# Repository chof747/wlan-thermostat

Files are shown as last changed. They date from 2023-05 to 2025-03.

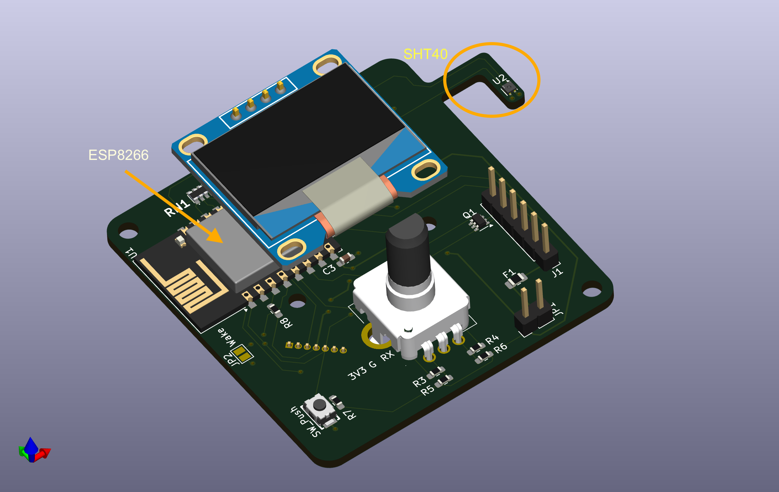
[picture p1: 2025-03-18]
temp_issue/wlan-thermo-front-panel-1.png

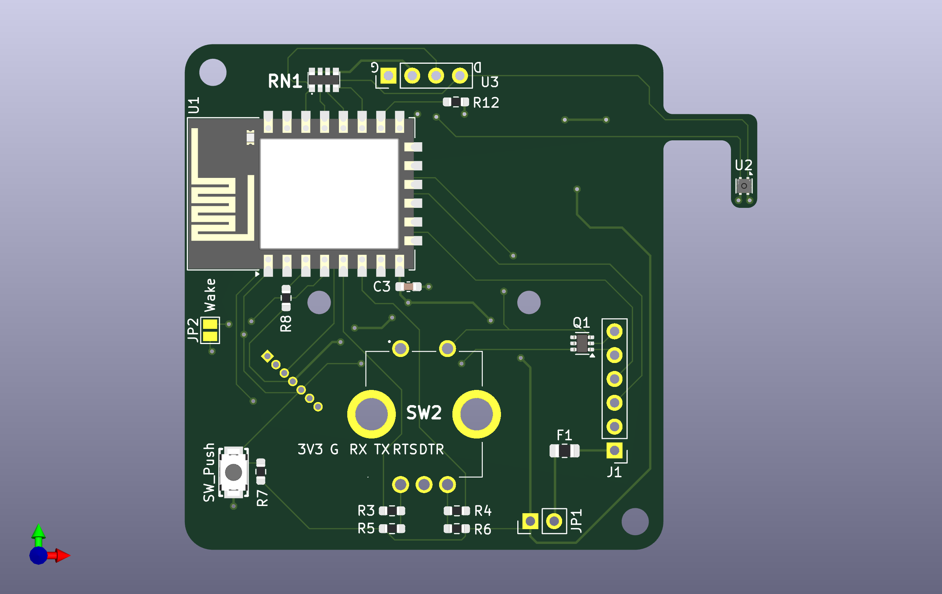
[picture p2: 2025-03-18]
temp_issue/wlan-thermo-front-panel-2.png

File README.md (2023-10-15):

## wlan-thermostat
Wireless Thermostats for elecrically triggerd heatings

This is the front panel of a wireless triggered heating which can be connected to a second board that contains the 
power supply and a relais capeable of switching the required electrical load. The front panel is designed to be
attached in a perpendicular way to the back part.

### Elements:

- An ESP8266-12F module containing the microcontroller, Flash
- A SHT40 temperature and humidity sensor
- A rotary encoder for input
- A SSD1306 OLED display for output
- Voltage regulator to regulate the 5V from the back board to 3v3 for the ESP8266 
- Programming logic and headers
- Headers to connect to the back board for power control and relay switching

## Used Parts:

## Revision History:

- **v1.0**: Initial version (Produced: 12.06.2023; First assembled: 29.06.2023)
- **v1.1**: Fixing after component testin (Produced: 15.07.2023; First assembled: 31.07.2023 / Frontend)
   1. Frontend:
     - Fixing of strapping pins of ESP-12F
     - Fixing of thermocoupling between ESP-12F and the temperature sensor
     - Introduction of UMH3N chip to replace two transistors + two resistors for the auto-reset circuit
     - Introduced resistor array to manage strapping pins
     - Switching of pins as follows:
         - Rotary Encoder Button now GPIO0 (doubling as a fallback mode for programming)
         - Relay pin: GPIO13

   2. Backend
     - Fixed orientation of Relay Footprint
     - Fixed size of footprint for optocoppler
     - Changed pinheaders for frontend connection from smd to throughole
     - Rearranged board placing to manage changed footprints
- **v1.2**: Alternate version without (exposed) ground panel at the back of the frontend thermo sensor
- **v1.3b**: Moved the temperature sensor to a sidearm sticking out of the board (produced 18.09.2023)
- **v1.2 (backend)**: Corrected pin order of transistor switching relay (Produced: 15.10.2023)

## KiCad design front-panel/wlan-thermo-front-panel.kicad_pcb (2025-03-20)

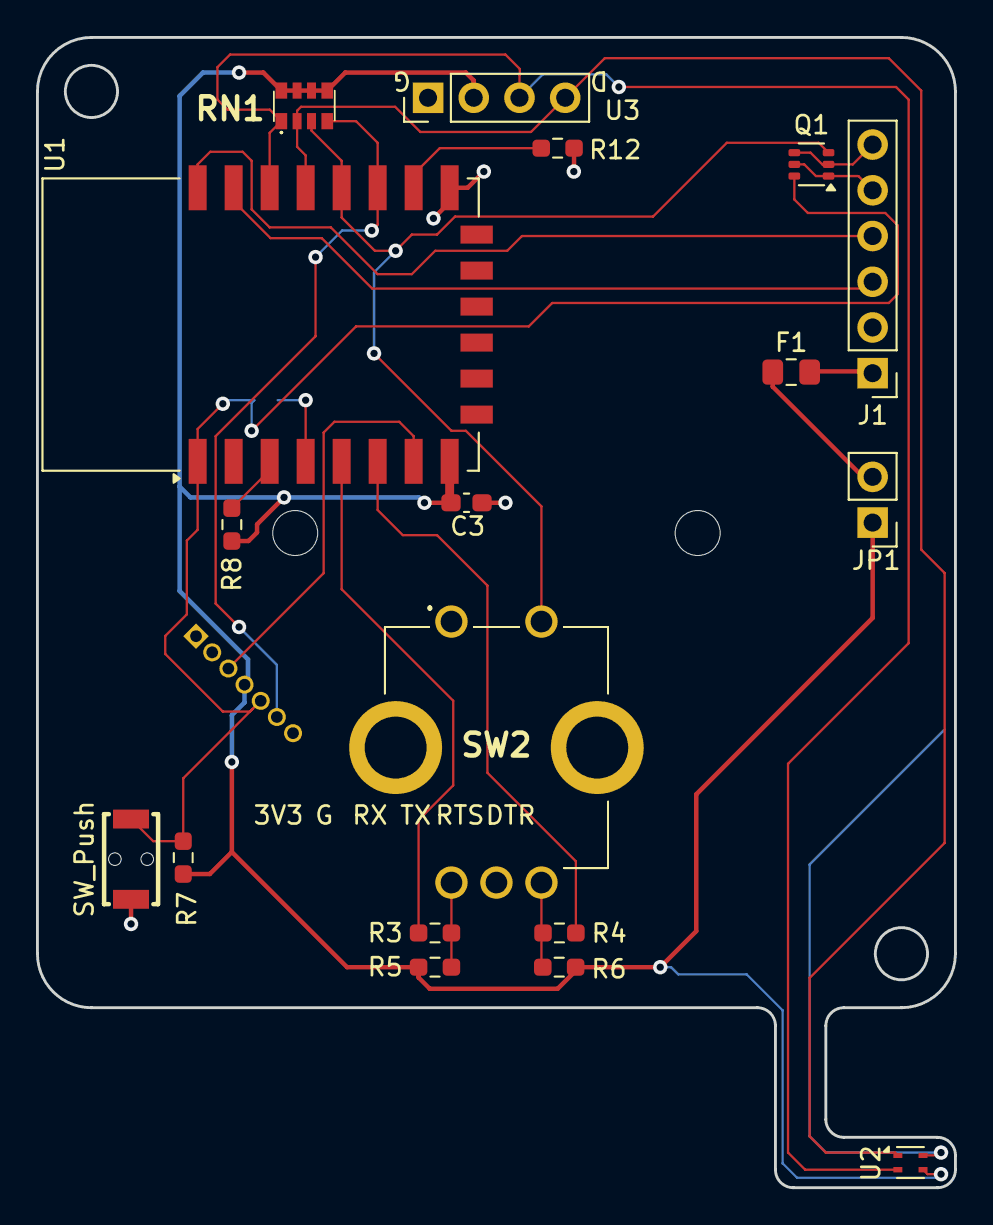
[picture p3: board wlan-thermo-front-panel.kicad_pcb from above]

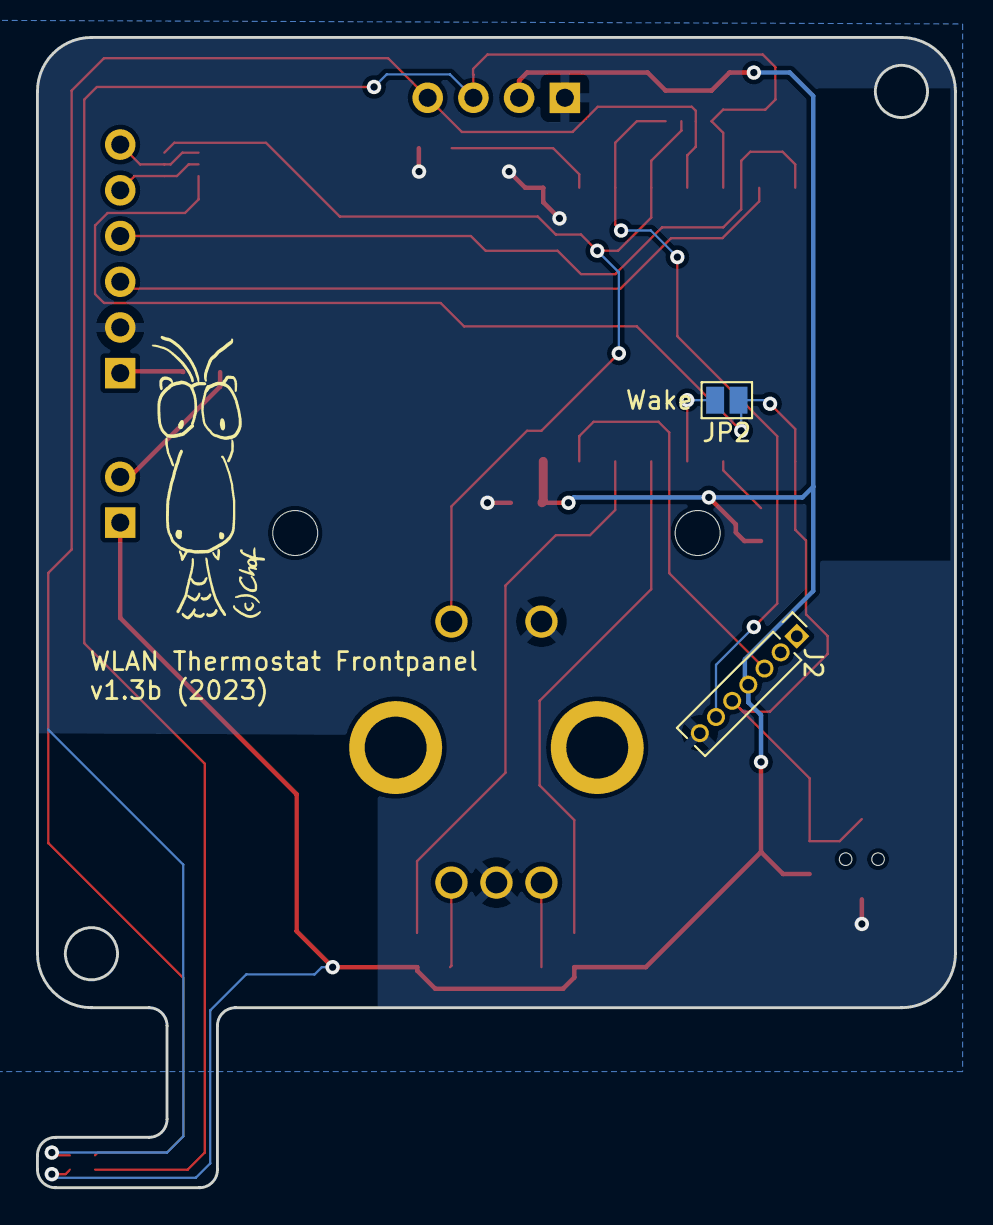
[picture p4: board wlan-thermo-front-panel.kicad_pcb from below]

Board: 2 copper layers, 51.0 x 63.9 mm, 20 parts (2 on the bottom side), 21 nets.

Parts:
C3: 10uF; C_0603_1608Metric_Pad1.08x0.95mm_HandSolder
F1: Fuse; Fuse_0805_2012Metric_Pad1.15x1.40mm_HandSolder
J1: PROG_HDR; PinHeader_1x06_P2.54mm_Vertical
J2: Device Connector; PinHeader_1x07_P1.27mm_Vertical
JP1: PWR_PROG; PinHeader_1x02_P2.54mm_Vertical
JP2: Wake; SolderJumper-2_P1.3mm_Open_Pad1.0x1.5mm
Q1: UMH3N; SOT-363_SC-70-6
R3, R4: 1k; R_0603_1608Metric_Pad0.98x0.95mm_HandSolder
R5, R6: 22k; R_0603_1608Metric_Pad0.98x0.95mm_HandSolder
R7, R8, R12: 10k; R_0603_1608Metric_Pad0.98x0.95mm_HandSolder
RN1: 10k; YC164JR07220RL
SW1: SW_Push; KEY-SMD_L3.9-W3.0-LS5.0-EH
SW2: RotaryEncoder_Switch; PEC12R3120FS0012
U1: ESP-12F; ESP-12E
U2: SHT4x; Sensirion_DFN-4_1.5x1.5mm_P0.8mm_SHT4x_NoCentralPad
U3: SSD1306; AZ Delivery SS1306 OLED

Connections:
+3V3: C3.1, J2.4, JP1.1 (A), R5.2, R6.2, R7.1, R8.1, RN1.5, RN1.6, RN1.7, RN1.8, U1.8 (VCC), U2.3 (VDD), U3.2 (VCC)
/3v3PROG: F1.2, J1.1
/3v3PROG_SAVE: F1.1, JP1.2 (B)
DTR: J1.6, Q1.2 (B1), Q1.4 (E2)
GND: C3.2, J1.2, J2.7, R12.2, SW1.2, SW2.1 (COM), SW2.C1 (COMMON), U1.15 (GND), U2.4 (VSS), U3.1 (GND)
GPIO2_RELAY: J2.6, RN1.4, U1.17 (GPIO2)
GPIO3_RX: J1.3, U1.21 (GPIO3/RXD)
GPIO4_SDA: RN1.2, U1.19 (GPIO4), U2.1 (SDA), U3.4 (SDA)
GPIO4_TX: J1.4, U1.22 (GPIO1/TXD)
GPIO5_SCL: RN1.1, U1.20 (GPIO5), U2.2 (SCL), U3.3 (SCL)
GPIO12_RENDAT: R4.1, U1.6 (GPIO12)
GPIO13_RX1: J2.3, U1.7 (GPIO13)
GPIO14_RENCLK: R3.1, U1.5 (GPIO14)
GPIO16_WAKE: JP2.2 (B), U1.4 (GPIO16)
unnamed: R3.2, R5.1, SW2.A1 (CHANNEL_A)
unnamed: R4.2, R6.1, SW2.B1 (CHANNEL_B)
unnamed: R8.2, U1.3 (EN)
unnamed: R12.1, U1.16 (GPIO15)
RTS: J1.5, Q1.1 (E1), Q1.5 (B2)
~GPIO0_RENBTN_FLASH: Q1.3 (C2), RN1.3, SW2.2 (NO), U1.18 (GPIO0)
~RESET: J2.5, JP2.1 (A), Q1.6 (C1), R7.2, SW1.1, U1.1 (~RST)

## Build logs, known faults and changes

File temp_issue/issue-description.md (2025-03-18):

## Situation:

I am currently designing a wifi enabled thermostat for an electric heating which consists of

1. a shelly 1 plus to switch the mains of the heating and to provide as a power supply for the controller (I am mitigating the GND connected to mains with a fully enclosed cover)
2. a self designed board featuring an **ESP12-F** module as MCU, a Rotary Encoder and an OLED for controlling and an **SHT40-AD1B-R2** temperature and humidity sensor for sensing the temp in the room

Both modules are going to be installed in the wall and are in a 3d printed enclosure consiting of a wall plate, holding the shelly and the PCB a cover closing all up and a skirt around the cover that contains the sensor, which sits on a small arm protruding from the PCB.

## Issue:

The SHT40 in the enclosure (with or without the skirt attached) is not measuring the temperature correctly but seems to be mainly driven by the temperature of the PCB material, the enclosure or the copper of the traces.

I have already taken some measurest to fix this problem, but they are not working 100%:

- The sensor sits on a side arm, which puts it outside of the core of the enclosure
- I have removed the ground plane in the vicinity of the arm to avoid heat conduction via this

But still it is picking up enough heat (I guess from the ESP) to distort the results in a way that I cannot compensate it.

Does anyone have any ideas how I can fix this? 

Attached are a few pictures, two from the 3D model of the PCB with the OLED attached, one from the PCB layout and a picture of the PCB in the enclosure. I would really appriciate any help or suggestions.

Thanks
Christian

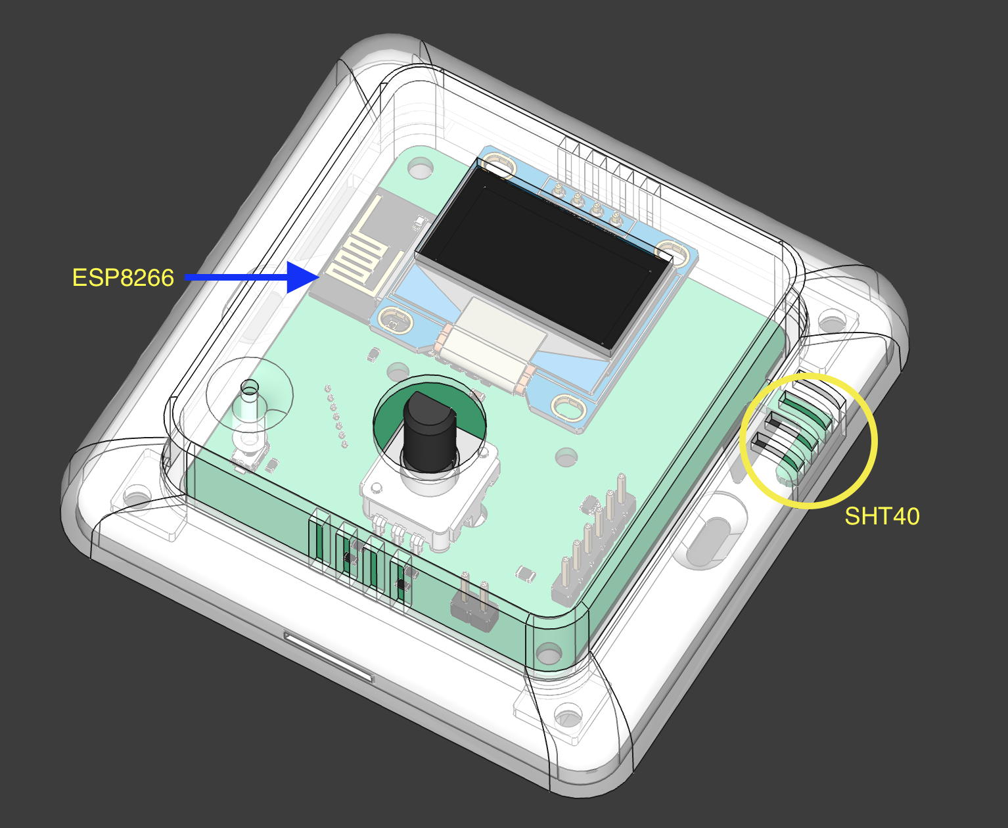
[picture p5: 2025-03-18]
temp_issue/module-in-enclosure.png

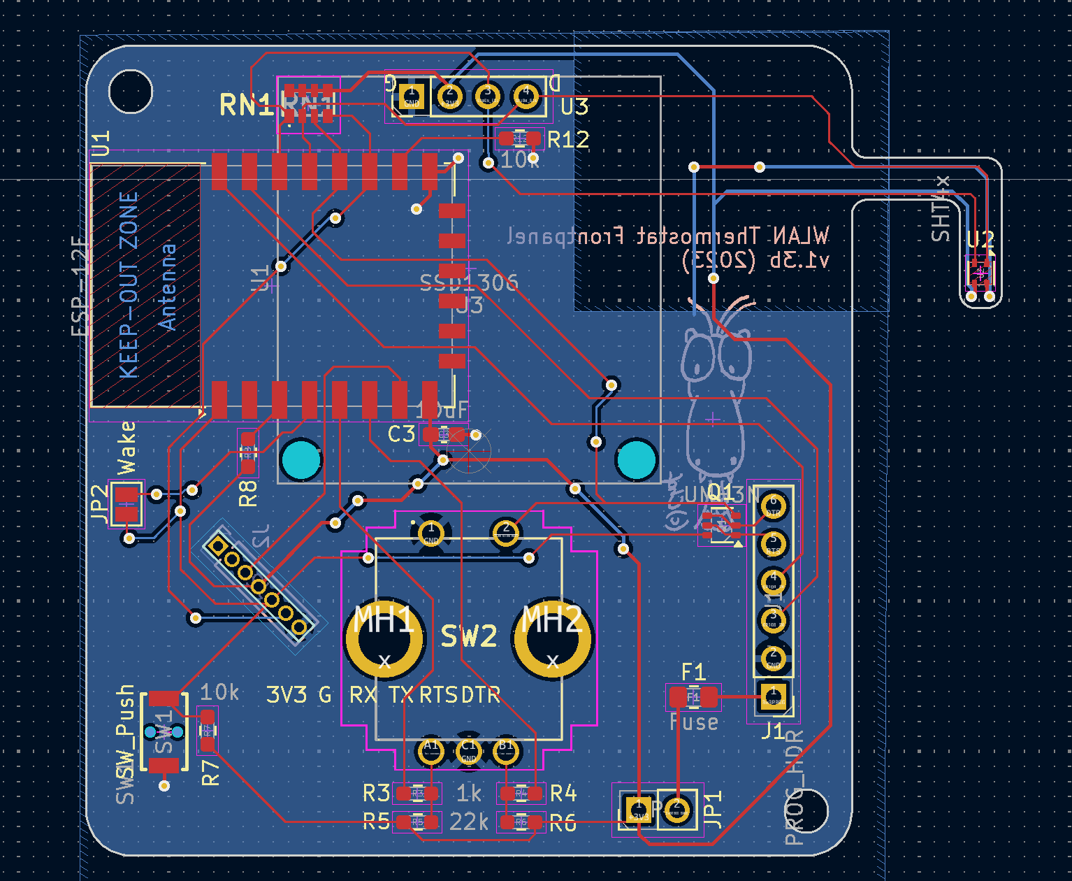
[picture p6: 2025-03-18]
temp_issue/wlan-thermostat-frontend-pcb-layout.png

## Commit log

2023-04-27 initial setup
    [wlan-thermostat.kicad_pcb, wlan-thermostat.kicad_sch]
2023-04-27 Updated template for KiCAD 7
    [wlan-thermostat.kicad_pcb, wlan-thermostat.kicad_sch]
2023-05-02 Initial board version
    [wlan-thermostat.kicad_pcb, wlan-thermostat.kicad_sch]
2023-05-04 Changed board size to fit into standard frame for power outlet
    [wlan-thermostat.kicad_pcb]
2023-05-11 created subdirs for front and back panel. First version of back panel
    [bom.csv, designators.csv, positions.csv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]
2023-05-14 First version fitting together
    [bom.csv, designators.csv, positions.csv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]
2023-05-31 Corrected traces and spacings for assembly
    [wlan-thermo-back-control.kicad_pcb, wlan-thermo-front-panel.kicad_pcb]
2023-07-02 Fixed strapping pins for booting and loading
    [wlan-thermo-front-panel.kicad_pcb, wlan-thermo-front-panel.kicad_sch]
2023-07-04 Decoupled sht40 from main ground plane
    In order to measure the ambient temperature and not the board one
    the following measures where taken:
    - Remove the ground plane from the area around the sensor
    - Turn all connections around so that a cut-out can be drawn around the component
    - Expose the copper on the back of the sensor's ground plane as additional heat disipation
    [wlan-thermo-front-panel.kicad_pcb]
2023-07-08 Changed strapping pins to resistor network
    [wlan-thermo-front-panel.kicad_pcb, wlan-thermo-front-panel.kicad_sch]
2023-07-09 Use UMH3N chip for autorestart cycle
    - Removed Q1/Q2 and the two 10k resistors and replace it with UMH3N for autoreset
    - Changed footprint of fuse to 0804
    - Reorganised board to be smaller to fit into casing of existing wall switch
    [wlan-thermo-front-panel.kicad_pcb, wlan-thermo-front-panel.kicad_sch]
2023-07-10 Corrected wrongly placed footprint for relay
    [wlan-thermo-back-control.kicad_pcb, wlan-thermo-back-control.kicad_sch]
2023-07-12 removed solder mask over backside of contacts
    [wlan-thermo-back-control.kicad_pcb]
2023-07-12 Changed relay pin to avoid on on flash and boot
    - Change relay pin to GPIO 13
    - Change Rotary encoder pin to GPIO0 (also pulled up and provides extra feature: Rotary button works as flash button)
    [wlan-thermo-front-panel.kicad_pcb, wlan-thermo-front-panel.kicad_sch]
2023-07-15 Revised optocopler footprint
    [wlan-thermo-back-control.kicad_pcb, wlan-thermo-back-control.kicad_sch]
2023-07-15 Redid whole for creeping protection of power supply
    - Changed frontend connectors also to throughole pins
    [wlan-thermo-back-control.kicad_pcb, wlan-thermo-back-control.kicad_sch]
2023-07-15 Merging of first revision round after component testing
    [wlan-thermo-back-control.kicad_pcb]
2023-08-19 Removed (exposed) ground plane from sensor area (rev 1.2)
    [wlan-thermo-front-panel.kicad_pcb]
2023-09-18 Version 1.3b with side arm for temp sensor
    [wlan-thermo-front-panel.kicad_pcb]
2023-10-15 Correcrted relay switching transistor pins
    [wlan-thermo-back-control.kicad_pcb, wlan-thermo-back-control.kicad_sch]
2024-02-10 Added board outlines
    [wlan-thermo-back-control.kicad_pcb, wlan-thermo-front-panel.kicad_pcb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]
2024-03-14 upgrade to KiCad 8.0
    [wlan-thermo-back-control.kicad_pcb, wlan-thermo-back-control.kicad_sch, wlan-thermo-front-panel.kicad_pcb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]
2024-12-26 removed gerber artifacts
    [wlan-thermo-front-panel-F_Paste.gbr, wlan-thermo-front-panel-job.gbrjob]
2024-12-26 removed backend board as it is not needed in this version
    [wlan-thermo-back-control.kicad_pcb, wlan-thermo-back-control.kicad_sch]
2024-12-26 crc checked first version of board with backend shelly
    [wlan-thermo-front-panel.kicad_pcb, wlan-thermo-front-panel.kicad_sch]
2025-03-18 minor changes
    [wlan-thermo-front-panel.kicad_pcb, wlan-thermo-front-panel.kicad_sch]
2025-03-20 Changed position of temp sensor
    Moved temp sensor to the bottom
    Replaced and rerouted other components
    [wlan-thermo-front-panel.kicad_pcb]
